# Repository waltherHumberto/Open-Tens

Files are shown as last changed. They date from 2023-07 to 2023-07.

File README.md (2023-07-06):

# Open-Tens
The goal of this project is to develop an open-source Transcutaneous Electrical Nerve Stimulation (TENS) system. TENS is a therapeutic technique that involves the application of low-voltage electrical currents to the skin, primarily for pain relief. This project aims to provide a platform for individuals and healthcare professionals to build and customize their own TENS devices using readily available hardware components.

The open-source nature of this project encourages collaboration, innovation, and the sharing of knowledge among developers and users. By making the TENS system accessible to a wider audience, we hope to empower individuals to explore alternative pain management techniques and contribute to the advancement of TENS technology.

Key Features and Objectives:

    Hardware Design: The project will provide detailed documentation and schematics for designing and building a TENS device. The emphasis will be on using affordable and easily obtainable components, making it accessible to hobbyists, researchers, and healthcare professionals.

    Software Development: The project will include software libraries and interfaces to control the TENS device. The software will allow users to adjust parameters such as frequency, pulse width, and intensity, providing a customizable and user-friendly experience.

    Safety and Effectiveness: Ensuring the safety and efficacy of the TENS system is of utmost importance. The project will focus on providing guidelines, best practices, and recommendations for safe usage, including electrical safety precautions and appropriate electrode placement.

    Community and Collaboration: The project aims to foster a supportive and collaborative community of developers, researchers, and users. This will be achieved through an online forum, issue tracking system, and regular updates to encourage discussions, bug reporting, feature requests, and contributions from the community.

By creating an open-source TENS system, we hope to democratize access to this pain management technique, encourage further research and development, and improve the lives of individuals suffering from chronic pain. Join us in this journey of innovation, empowerment, and open science.

Note: This project is not intended to replace professional medical advice or treatment. Users should consult with healthcare professionals before using the TENS system for any medical conditions or concerns.

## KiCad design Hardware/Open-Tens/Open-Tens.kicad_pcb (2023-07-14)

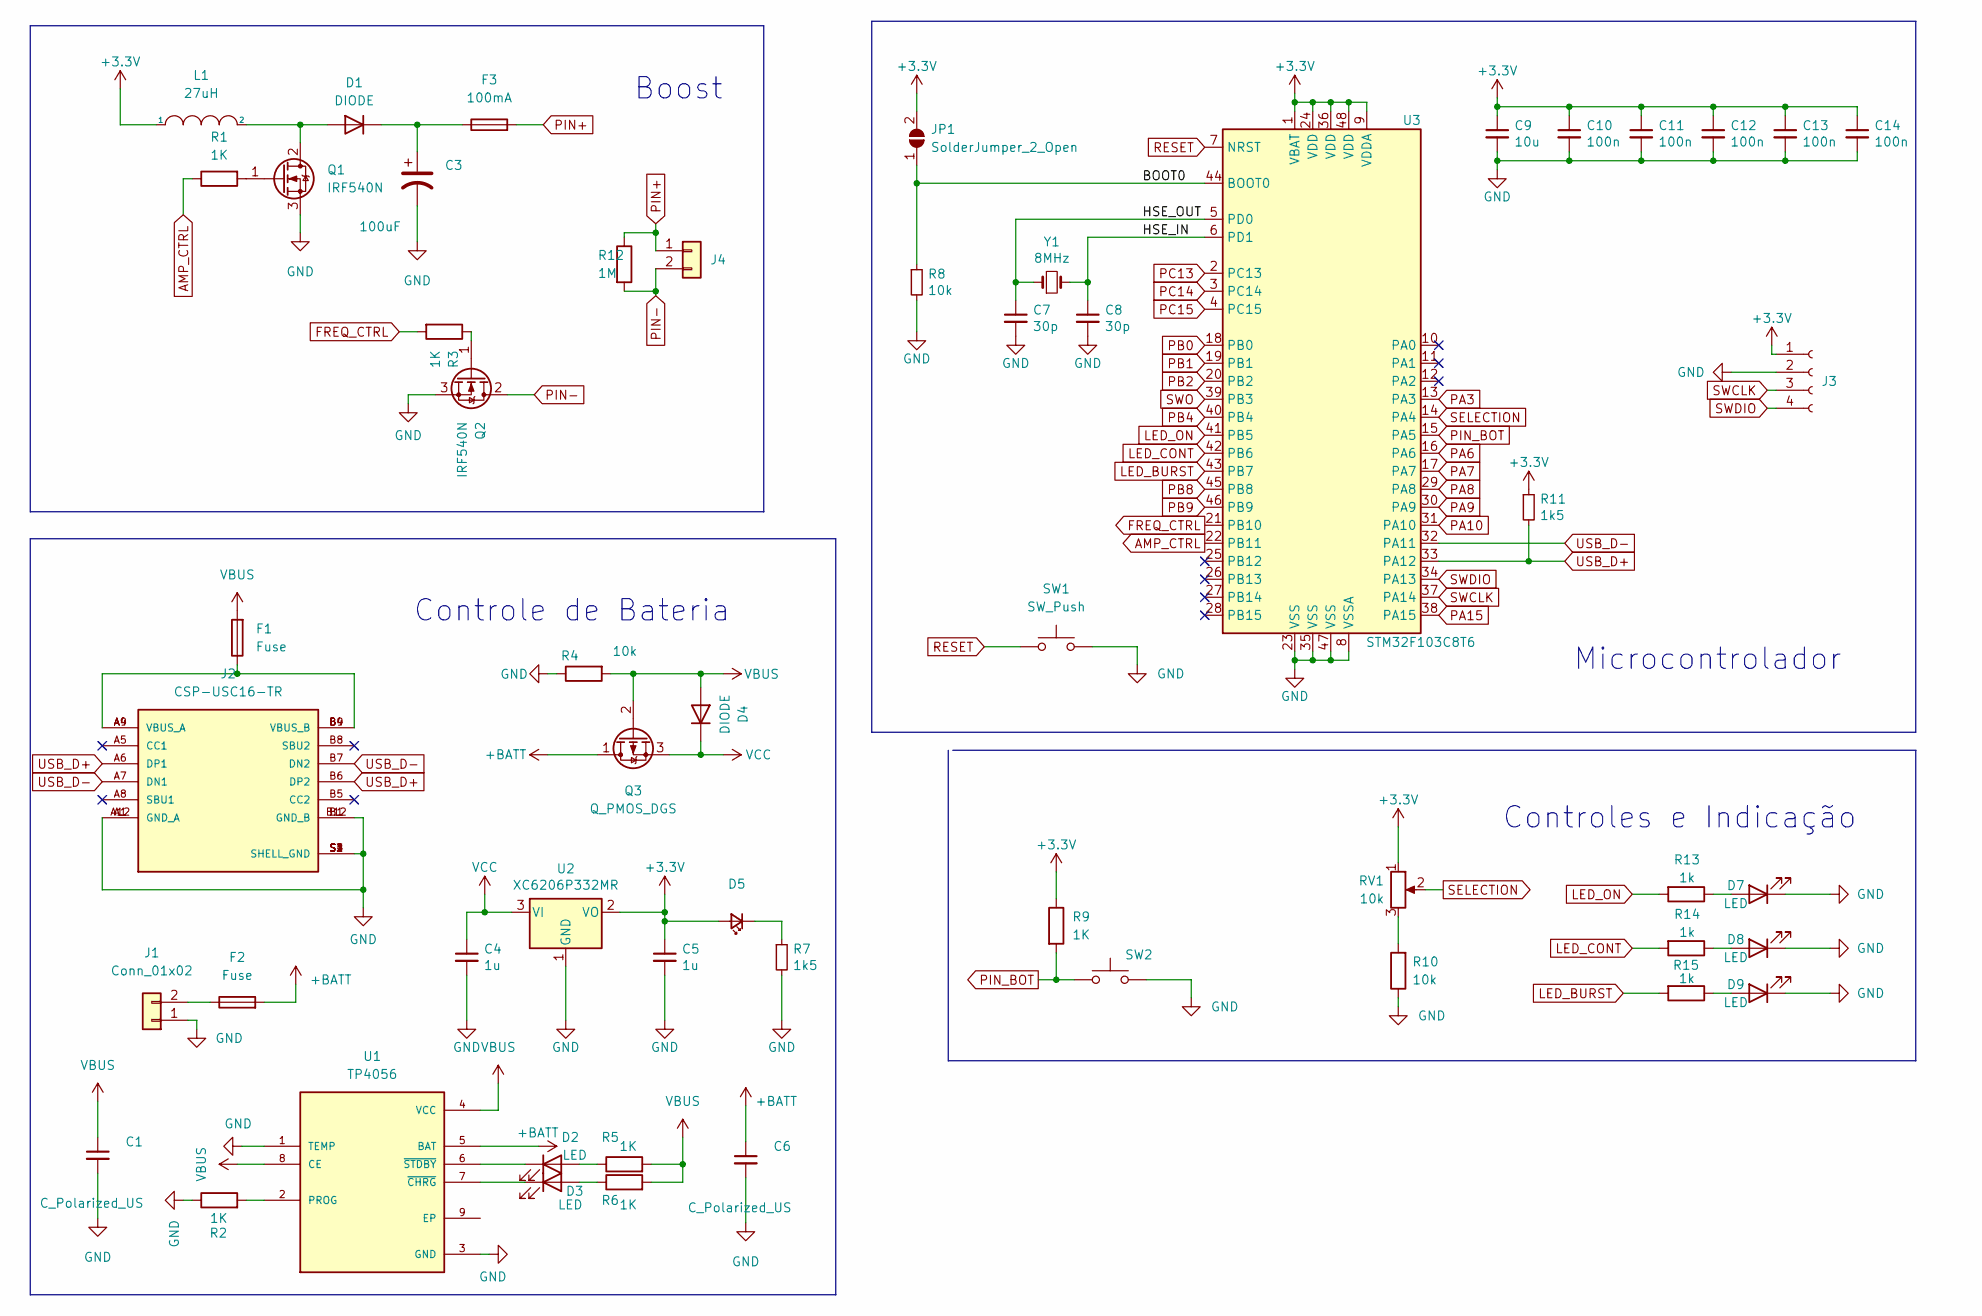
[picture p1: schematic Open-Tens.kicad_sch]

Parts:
C1, C6: C_Polarized_US; C_1210_3225Metric
C3: 100uF; CP_Radial_D10.0mm_P7.50mm
C4, C5: 1u; C_0603_1608Metric; LCSC Part # C15849
C7, C8: 30p; C_0402_1005Metric; LCSC Part # C1570
C9: 10u; C_1210_3225Metric; LCSC Part # C19666
C10, C11, C12, C13, C14: 100n; C_0402_1005Metric; LCSC Part # C1525
D1, D4: DIODE; D_1210_3225Metric
D2, D3, D7, D8, D9: LED; LED_D5.0mm_FlatTop
D5: LED; LED_D5.0mm_FlatTop; LCSC Part # C72043
F1, F2: Fuse; R_1206_3216Metric
F3: 100mA; R_1206_3216Metric
J1: Conn_01x02; PinSocket_1x02_P2.54mm_Vertical
J2: CSP-USC16-TR; USB_C_Receptacle_Palconn_UTC16-G; PARTREV A0
J3: Conn_01x04_Female; PinSocket_1x04_P2.54mm_Vertical
J4: Conn_01x02; R_Axial_DIN0309_L9.0mm_D3.2mm_P12.70mm_Horizontal
JP1: SolderJumper_2_Open; PinSocket_1x02_P2.54mm_Vertical
L1: 27uH; L_Taiyo-Yuden_NR-80xx_HandSoldering
Q1, Q2: IRF540N; TO-220-3_Vertical
Q3: Q_PMOS_DGS; SOT-23-3
R1, R2, R3, R5, R6, R9: 1K; R_0603_1608Metric
R4, R10: 10k; R_0603_1608Metric
R7: 1k5; R_0603_1608Metric; LCSC Part # C22843
R8: 10k; R_0603_1608Metric; LCSC Part # C25744
R11: 1k5; R_0603_1608Metric; LCSC Part # C25867
R12: 1M; R_Axial_DIN0309_L9.0mm_D3.2mm_P12.70mm_Horizontal
R13, R14, R15: 1k; R_0603_1608Metric
RV1: 10k; Potentiometer_Bourns_3296W_Vertical
SW1, SW2: SW_Push; SW_Push_1P1T_NO_CK_KSC6xxJ
U1: TP4056; SOP-8_3.9x4.9mm_P1.27mm
U2: XC6206P332MR; SOT-23; LCSC Part # C5446
U3: STM32F103C8T6; LQFP-48_7x7mm_P0.5mm; LCSC Part # C8734
Y1: 8MHz; Crystal_SMD_5032-2Pin_5.0x3.2mm; LCSC Part # C115962

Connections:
+3.3V: C5.1, C9.1, C10.1, C11.1, C12.1, C13.1, C14.1, D5.2 (A), J3.1, JP1.2 (B), L1.1, R9.1, R11.1, RV1.1, U2.2 (VO), U3.1 (VBAT), U3.9 (VDDA), U3.24 (VDD), U3.36 (VDD), U3.48 (VDD)
+BATT: C6.1, F2.2, Q3.1 (D), U1.5 (BAT)
/BOOT0: JP1.1 (A), R8.1, U3.44 (BOOT0)
/HSE_IN: C8.1, U3.6 (PD1), Y1.2
/HSE_OUT: C7.1, U3.5 (PD0), Y1.1
AMP_CTRL: R1.1, U3.22 (PB11)
FREQ_CTRL: R3.2, U3.21 (PB10)
GND: C1.2, C3.2, C4.2, C5.2, C6.2, C7.2, C8.2, C9.2, C10.2, C11.2, C12.2, C13.2, C14.2, D7.1 (K), D8.1 (K), D9.1 (K), J1.1, J2.A1 (GND_A), J2.A12 (GND_A), J2.B1 (GND_B), J2.B12 (GND_B), J2.S1 (SHELL_GND), J2.S2 (SHELL_GND), J2.S3 (SHELL_GND), J2.S4 (SHELL_GND), J3.2, Q1.3 (S), Q2.3 (S), R2.1, R4.1, R7.2, R8.2, R10.1, SW1.2, SW2.2, U1.1 (TEMP), U1.3 (GND), U2.1 (GND), U3.8 (VSSA), U3.23 (VSS), U3.35 (VSS), U3.47 (VSS); also elsewhere on the board
LED_BURST: R15.2, U3.43 (PB7)
LED_CONT: R14.2, U3.42 (PB6)
LED_ON: R13.2, U3.41 (PB5)
unnamed: C3.1, D1.2 (K), F3.1
unnamed: D1.1 (A), L1.2, Q1.2 (D)
unnamed: D2.1 (K), U1.6 (~STDBY)
unnamed: D2.2 (A), R5.1
unnamed: D3.1 (K), U1.7 (~CHRG)
unnamed: D3.2 (A), R6.1
unnamed: D5.1 (K), R7.1
unnamed: D7.2 (A), R13.1
unnamed: D8.2 (A), R14.1
unnamed: D9.2 (A), R15.1
unnamed: F1.1, J2.A4 (VBUS_A), J2.A9 (VBUS_A), J2.B4 (VBUS_B), J2.B9 (VBUS_B)
unnamed: F2.1, J1.2
unnamed: Q1.1 (G), R1.2
unnamed: Q2.1 (G), R3.1
unnamed: R2.2, U1.2 (PROG)
unnamed: R10.2, RV1.3
PA3: U3.13 (PA3)
PA6: U3.16 (PA6)
PA7: U3.17 (PA7)
PA8: U3.29 (PA8)
PA9: U3.30 (PA9)
PA10: U3.31 (PA10)
PA15: U3.38 (PA15)
PB0: U3.18 (PB0)
PB1: U3.19 (PB1)
PB2: U3.20 (PB2)
PB4: U3.40 (PB4)
PB8: U3.45 (PB8)
PB9: U3.46 (PB9)
PC13: U3.2 (PC13)
PC14: U3.3 (PC14)
PC15: U3.4 (PC15)
PIN+: F3.2, J4.1, R12.1
PIN-: J4.2, Q2.2 (D), R12.2
PIN_BOT: R9.2, SW2.1, U3.15 (PA5); also elsewhere on the board
RESET: SW1.1, U3.7 (NRST); also elsewhere on the board
SELECTION: RV1.2, U3.14 (PA4)
SWCLK: J3.3, U3.37 (PA14)
SWDIO: J3.4, U3.34 (PA13)
SWO: U3.39 (PB3)
USB_D+: J2.A6 (DP1), J2.B6 (DP2), R11.2, U3.33 (PA12)
USB_D-: J2.A7 (DN1), J2.B7 (DN2), U3.32 (PA11)
VBUS: C1.1, D4.1 (A), F1.2, Q3.2 (G), R4.2, R5.2, R6.2, U1.4 (VCC), U1.8 (CE)
VCC: C4.1, D4.2 (K), Q3.3 (S), U2.3 (VI)

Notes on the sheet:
Controle de Bateria
Controles e Indicação
Boost
Microcontrolador

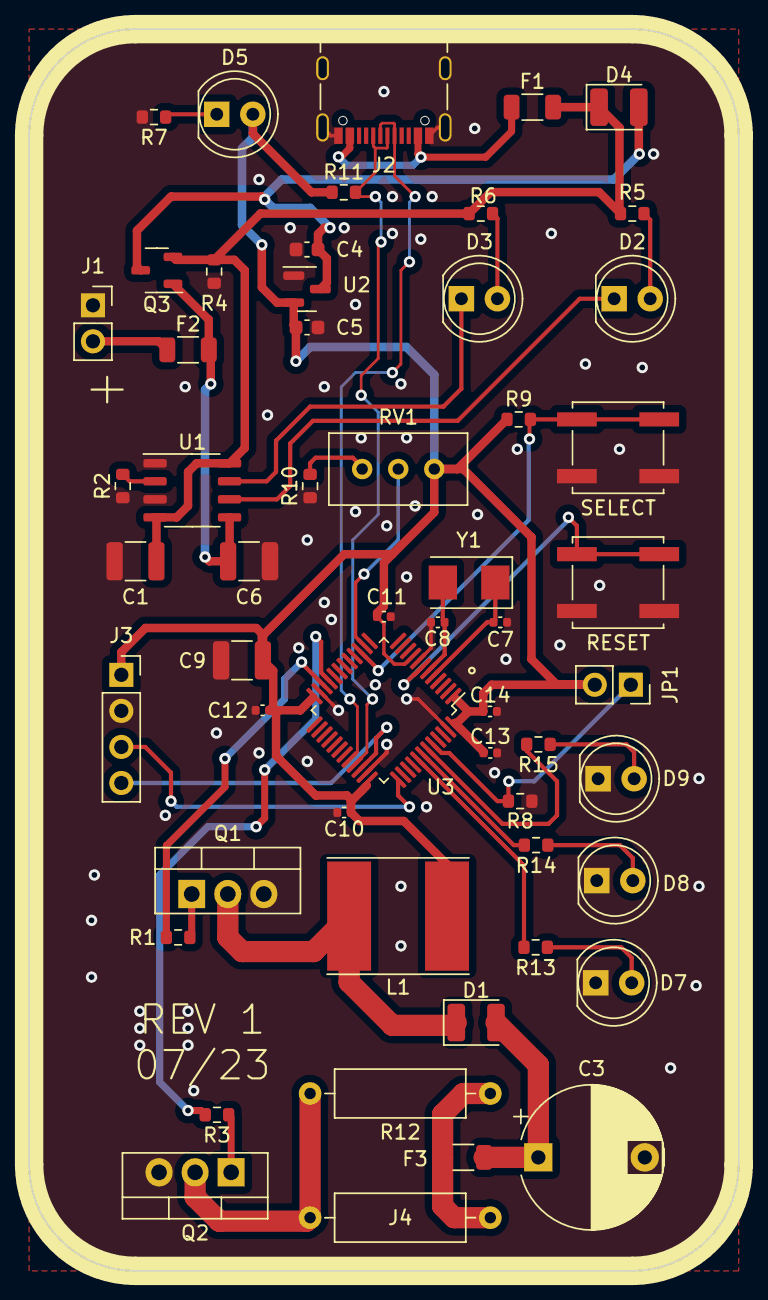
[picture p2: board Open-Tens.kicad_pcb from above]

Board: 2 copper layers, 50.0 x 87.5 mm, 55 parts (0 on the bottom side), 38 nets.

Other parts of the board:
RESET: SW_Push; SW_Push_1P1T_NO_CK_KSC6xxJ
SELECT: SW_Push; SW_Push_1P1T_NO_CK_KSC6xxJ

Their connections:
GND: RESET.2, SELECT.2; also elsewhere on the board
PIN_BOT: SELECT.1; also elsewhere on the board
RESET: RESET.1; also elsewhere on the board

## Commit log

2023-07-09 Saving to push
    [Open-Tens.kicad_pcb, Open-Tens.kicad_sch]
2023-07-11 Separando o esquematico falta colocar valores
    [Open-Tens.kicad_sch]
2023-07-13 Trocando o micro para stm32
    [Open-Tens.kicad_sch]
2023-07-13 Comecei a colocar alguns footprints
    [Open-Tens.kicad_pcb, Open-Tens.kicad_sch]
2023-07-14 Fiz um roteamento completo mas vou revisar e refazer
    [Open-Tens-B_Cu.gbr, Open-Tens-B_Mask.gbr, Open-Tens-B_Paste.gbr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]
